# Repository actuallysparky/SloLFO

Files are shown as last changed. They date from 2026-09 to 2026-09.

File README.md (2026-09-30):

# SloLFO

SloLFO is an 8 HP slow Eurorack LFO module and a VCV Rack 2 plugin. The VCV plugin is availalbe prior to the eurorack module and is being used as an exploring ground for the user interface. Three phase-aligned outputs provide sine, triangle, and square CV. The module uses one push encoder and an 8×8 color matrix modeled on the Waveshare RP2350-Matrix hardware fork.

**Author for the VCV plugin: Bearamin.** Inspired by Patience, with thanks to the wonders of slow time.

## Try the VCV module

| Action | Result |
| --- | --- |
| Tap the encoder for under 0.5 seconds | Select Minutes, Hours, Days, or Months; the selected 4×4 color quadrant is bright. |
| Turn the encoder | Set 1–60 minutes, 1–24 hours, 1–64 days in half-day steps, or 1–64 fixed 30-day months. |
| Hold for 0.5 seconds | Preview the present voltage mode: four blue upper rows for 0–5 V, or blue upper and red lower rows for −5–5 V. |
| Continue holding to 2 seconds | Switch all three outputs immediately and update the preview; a longer hold does not switch again. |

Minutes and Hours show period as a colored pie. Days and Months fill the grid from the upper left, one pixel per day or month; half-day settings half-light the next pixel. At idle, a colored triangle remains static while one bright pixel follows phase. Its upper-half shape indicates unipolar output; bipolar uses the display's full height. The three CV outputs remain active together.

The plugin is a user-experience prototype. A fixed month is 30 days, so the longest setting is 1,920 days. The included firmware now targets the RP2350/8×8 module and follows the same front-panel controls and displays. Physical behavior remains to be checked on an assembled module.

## Contents

- [`vcv/`](vcv/) — Rack plugin C++ source, panel SVG, manifest, build files, and panel generator.
- [`firmware/`](firmware/) — RP2350/8×8 firmware source, local board definition, and build instructions.
- [`hardware/`](hardware/) — RP2350 carrier and 8×8 faceplate KiCad PCB files plus the custom footprints they use.
- [`bom/`](bom/) — a current board-derived parts list and an older priced Rev B workbook, with revision notes.
- [`docs/functional-spec.md`](docs/functional-spec.md) — proposed behavior and electrical architecture.
- [`docs/2350-fork-notes.md`](docs/2350-fork-notes.md) — RP2350 pin mapping and open hardware issues.

## Build the Rack plugin

Install the VCV Rack 2 plugin SDK and set `RACK_DIR` to its extracted `Rack-SDK` directory. The checked-in panel SVG lets a normal plugin build use the existing artwork; regenerating it from the faceplate requires KiCad's `kicad-cli` and Python 3.

```sh
cd vcv
make RACK_DIR=/absolute/path/to/Rack-SDK
make dist RACK_DIR=/absolute/path/to/Rack-SDK
```

The `.vcvplugin` package appears under `vcv/dist/`. The plugin manifest uses the `SlowLFOPrototype` slug and `Bearamin` author. The checked-in panel SVG is packaged as-is; run `make -C vcv panel` when the KiCad faceplate changes.

For a release package built from the current committed source, run:

```sh
RACK_DIR=/absolute/path/to/Rack-SDK ./vcv/build_release.sh
```

This uses `git archive HEAD` in a temporary directory, builds with the supplied Rack 2 SDK, and writes the plugin archive plus a SHA-256 checksum to `_local/releases/v2.0.6/`. Use a Rack 2.6.6 SDK for the current release. The script requires a clean tracked tree so the resulting package can be tied to a commit. The `.vcvplugin` contains `plugin.json`, the panel artwork, and the GPL license; the separate RP2350 firmware is not part of the Rack package.

The manually triggered [cross-platform release workflow](.github/workflows/release-cross-platform.yml) builds Windows x64 and Linux x64 packages from the fixed `v2.0.6` tag with their matching Rack 2.6.6 SDKs, checks package contents, and attaches packages, checksums, and build details to the private GitHub release. The macOS ARM64 package is built with the local release script above.

On macOS systems whose default Command Line Tools SDK reports an `arm64e.x1` linker error, set `SDKROOT` to a compatible Xcode SDK. This release was built with `SDKROOT=/Applications/Xcode.app/Contents/Developer/Platforms/MacOSX.platform/Developer/SDKs/MacOSX26.5.sdk`. The script also writes `BUILDINFO.txt` with the source commit, SDK, compiler, and platform used.

## License and project status

SloLFO is licensed under [GPL-3.0-or-later](LICENSE), the license identifier used by [VCV Core](https://github.com/VCVRack/Rack/blob/v2/Core.json). TUpdates to the plugin, firmware, and boards will be published here as the design evolves. See the [firmware build and pin map](firmware/README.md) and [hardware files](hardware/README.md).

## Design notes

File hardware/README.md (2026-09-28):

# Hardware

`Slow-LFO-8HP-Carrier-RevB_2350.kicad_pcb` and `Slow-LFO-8HP-Faceplate_8x8.kicad_pcb` are the RP2350/8×8 carrier and faceplate designs. `SlowLFO.pretty` contains the custom footprints referenced by the carrier, and `fp-lib-table` points KiCad to that directory.

The boards are the current design files in this private development repository. The carrier has open electrical and fit work; fabrication and validation are the next hardware milestones. See [RP2350 fork notes](../docs/2350-fork-notes.md) and the [functional specification](../docs/functional-spec.md) for the pin map and circuit design.

Open either PCB in KiCad to inspect or continue the layout. The matching RP2350 firmware source is in `../firmware/`.

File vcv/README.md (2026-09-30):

# Slow LFO for VCV Rack 2

This 8HP virtual module previews the proposed 8×8 RGB user experience. It generates ideal phase-aligned sine, triangle, and square outputs in either 0–5 V or −5–5 V. Its panel SVG is generated from the `Slow-LFO-8HP-Faceplate_8x8.kicad_pcb` front silk and copper artwork. VCV models the controls and timing; the hardware firmware and circuit are developed separately.

## Use

- Click the encoder to advance Minutes → Hours → Days → Months. Four 4×4 color quadrants fill the matrix; the bright quadrant is selected.
- Drag the encoder vertically or scroll over it to change period. The ranges are 1–60 minutes, 1–24 hours, 1–64 days in half-day steps, and 1–64 fixed 30-day months. Minutes and Hours fill a colored pie. Days and Months fill the 8×8 grid from the upper left, one pixel per day or month; the next day pixel is half-bright at half-day steps. A full violet grid represents a 64-month cycle.
- Hold the encoder for 0.5 seconds to preview the current voltage mode: four blue upper rows for 0–5 V, or blue upper and red lower rows for −5–5 V. Keep holding to 2 seconds to switch all outputs immediately; the preview changes with them. Further holding does nothing. Release between 0.5 and 2 seconds to leave the mode unchanged. A tap shorter than 0.5 seconds still advances the edit unit.
- After two seconds, the matrix returns to a static triangle glyph in the selected unit's color. The glyph stays visibly colored while one white, extra-bright pixel follows the shared phase. In 0–5 V mode the glyph and marker stay in the upper four rows; in −5–5 V mode they span the full matrix. All three CV jacks remain active at all times.
- On module creation and after switching simulated power back on, a 64-pixel spiral shows reserve-capacitor charging. The default is 15 real seconds, with 10- and 25-second comparison settings in the context menu. Phase and encoder edits pause while charging; CV outputs hold the saved phase. Simulated power off blanks the matrix and drives the output jacks to 0 V. Time acceleration does not accelerate charging.
- The module context menu also exposes 1×/60×/3600×/86400× time acceleration, forced phase, and simulated power off/on. These extra controls are VCV-only.
- Open the context menu to see the exact period. Connect the three output jacks to Rack's Scope to inspect their voltages.

The physical hardware's present sine/triangle RC filters support a provisional **10-second minimum target** for usable shape. The revised 1-minute minimum has ample calculated margin, pending bench measurement. A fixed month means 30 days, not a calendar month; 64 months is 1,920 days. The selected 0.33 F capacitor and 10 Ω charge resistor give an ideal 3.3-second RC constant; the actual reserve-ready delay is estimated at roughly **10–25 seconds**. The 15-second VCV animation is a UX approximation, not a measured capacitor model.

## Build and install

Install a Rack 2 plugin SDK and pass its `Rack-SDK` directory as `RACK_DIR`. The SDK is a build dependency, not project source. The checked-in `res/SlowLFO.svg` is packaged directly, so a plugin build does not require KiCad. When the faceplate changes, run `make -C vcv panel` from the repository root and commit the regenerated SVG; that explicit step requires Python 3 and `kicad-cli`. Set `KICAD_CLI` to its executable if it is not on `PATH`.

```sh
cd vcv
make -j4 RACK_DIR=/absolute/path/to/Rack-SDK
make dist RACK_DIR=/absolute/path/to/Rack-SDK
```

`dist/` contains a `.vcvplugin` package. Rack loads installed plugins at startup; restart Rack after installation. The module appears as **Slow LFO Prototype → Slow LFO**.

For a release build from committed source, run `RACK_DIR=/absolute/path/to/Rack-SDK ./vcv/build_release.sh` from the repository root. The script places the package and SHA-256 checksum under `_local/releases/<version>/` and checks that the package contains the manifest, artwork, and license. The current release target uses Rack SDK 2.6.6 on macOS ARM64; other architectures require their corresponding Rack SDK and a build on that platform or the official Rack plugin toolchain.
The script also writes `BUILDINFO.txt`. If the host's default macOS SDK cannot link the plugin, set `SDKROOT` to a compatible Xcode SDK before invoking the script.

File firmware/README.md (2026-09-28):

# RP2350-Matrix firmware

This Pico SDK firmware targets the Waveshare RP2350-Matrix with its 8×8 RGB display and the SloLFO carrier. It implements the VCV module's four literal period units, encoder gestures, static triangle phase view, colored selector, pie/calendar period views, and simultaneous sine, triangle, and square outputs. The hardware charging spiral follows measured reserve voltage; VCV uses a timed simulation.

## Build

Use Pico SDK 2.3.1 or newer and an Arm embedded GCC toolchain. From the repository root, set `PICO_SDK_PATH` to a local SDK checkout and run:

```sh
cmake -S firmware -B /tmp/slolfo-rp2350-build -G Ninja -DCMAKE_BUILD_TYPE=Release -DPICO_NO_PICOTOOL=1
cmake --build /tmp/slolfo-rp2350-build -j4
```

The build creates `slow_lfo.elf` and `slow_lfo.bin` in the build directory. With a suitable `picotool`, omit `-DPICO_NO_PICOTOOL=1` and set `-DSLOW_LFO_UF2=ON` to request UF2 output. The local board header selects RP2350A and the module's nominal 16 MB flash. The post-build check keeps the binary out of the final 64 KiB flash journal.

## Controls and outputs

- A tap shorter than 0.5 seconds advances Minutes → Hours → Days → Months and shows four 4×4 color quadrants, with the selected quadrant bright.
- Turning sets 1–60 minutes in 1-minute steps, 1–24 hours in 1-hour steps, 1–64 days in half-day steps, or 1–64 fixed 30-day months in 1-month steps. The first detent in a new unit clamps an out-of-range period to that unit's nearest endpoint. The period display returns to the waveform after two seconds.
- From 0.5 seconds of a press, the matrix previews the current output mode: blue upper rows for 0–5 V; blue upper and red lower rows for −5–5 V. At two seconds the mode switches once, immediately. Turning while pressed cancels the hold action.
- Minutes and Hours fill a color pie. Days and Months fill from the upper-left in calendar order. The idle triangle has a bright moving phase pixel and occupies only the upper four rows in unipolar mode.

GP10/11/12 generate sine/triangle/square PWM; GP13/14/15 read encoder A/B/push; GP26 senses the buck rail; GP27 senses the reserve capacitor; GP25 drives the WS2812 chain. The code assumes alternating physical LED rows. The board's ADC divider ratios are provisionally 1:2; 4.4 V fail, 4.75 V recover, and 4.55 V reserve-ready are prototype thresholds. Confirm the actual LED orientation, rail thresholds, and PWM-to-jack voltages on the assembled board before using a binary.

One shared 64-bit timer phase drives all three outputs at 100 Hz. Charging freezes the phase and encoder edits until the reserve threshold is met. The phase also freezes while unpowered; no backed-up RTC is present. The final 64 KiB of flash holds 256-byte CRC journal records with period, phase, voltage mode, and selected unit. It checkpoints hourly and appends an emergency record after buck loss, without erasing during reserve power. A red lower-right pixel indicates a failed flash operation or an invalid record found at boot. The 16 MB flash capacity, one-second hold-up margin, and interrupted-write recovery still require physical confirmation.

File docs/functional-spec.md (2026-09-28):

# Slow LFO — Rev B functional specification

Status: engineering prototype. The 8×8 RP2350 carrier and 22 × 22 mm faceplate opening are separate forks of the earlier RP2040 design. See [RP2350 fork notes](2350-fork-notes.md). The UX contract below is implemented in the VCV module and RP2350 firmware source. Electrical, physical, and power-cut acceptance on a built unit remain open.

## Product and interface

An 8HP, 3U Eurorack module produces simultaneous, phase-aligned SINE, TRIANGLE, and SQUARE CVs on three 3.5 mm TS jacks. The new controller/display target is the Waveshare **RP2350-Matrix** with its 8×8 RGB matrix. The legacy RP2040/5×5 carrier and schematic remain separate references until the new fork is electrically completed. One five-terminal, detented push encoder is the only control. The display sits above the encoder; the three jacks are below it. No rate CV, sync, output attenuator, or phase-reset control is included.

### UX timing and encoder contract

The revised prototype period range is **1 minute through 64 fixed 30-day months** (165,888,000 seconds, about 5.26 years). The four edit units are literal **minutes, hours, days, and months**: a displayed minute count means that many minutes per cycle, and a displayed month count means that many months per cycle. A fixed month is provisionally 30 days; this keeps periods deterministic without a clock or calendar date. Period is stored as an exact duration in seconds; changing period preserves instantaneous phase and keeps the three outputs phase-aligned.

| Edit unit | Color role | Selectable period | Encoder detent |
| --- | --- | --- | --- |
| Minutes | Cyan | 1–60 min | 1 min |
| Hours | Green | 1–24 h | 1 h |
| Days | Amber | 1–64 d | 0.5 d; one pixel per day, with the next pixel half-bright at half days |
| Months | Violet | 1–64 fixed 30-day months | 1 month; one pixel per month |

Endpoints intentionally overlap at 60 min = 1 h, 24 h = 1 d, and 30/60 d = 1/2 fixed months. Days and Months both fill the 64 pixels in row-major order from the upper left. In Days, 1 d lights one pixel, 1.5 d lights the next pixel at half brightness, and 64 d fills the grid. In Months, 1 month lights one pixel and 64 months fills the grid. The earlier 25-to-30-day setting gap is gone. The VCV prototype uses an exact-value context-menu label for observation; no text or number is drawn on the hardware display.

At idle, the matrix shows **one static triangle glyph** in the selected unit's color. Its full shape stays visibly colored, while one extra-bright white pixel travels along it to show the shared cycle phase. In UNI (0 to +5 V), the entire glyph and marker occupy only rows 0–3, leaving rows 4–7 dark; in BI (−5 to +5 V), they span the full eight-row height. This is a visual indication of output range; the three jacks continue to output sine, triangle, and square simultaneously. A **short press** (<500 ms) advances the selected edit unit Minutes → Hours → Days → Months → Minutes, displays a four-quadrant color selector with the selected quadrant dramatically brighter, and does not itself change period or phase. Each quadrant fills one 4×4 corner of the matrix, so the selector uses all 64 pixels. Turning the encoder edits the selected unit and shows its full-screen time display. If the existing period is outside that unit's range, the first detent lands on the nearest boundary; later detents move by its listed step. When it is already in range, the first detent moves by one step. No detent wraps at an endpoint. After about two seconds without input, return to the idle glyph. Unit hue remains fixed across selection and time displays.

In Minutes and Hours, the **entire 8×8 matrix** is a circular pie whose illuminated area represents the chosen period as a fraction of that unit's maximum. Boundary-pixel brightness may show fractional fill, but the display is intentionally qualitative. In Days and Months, the matrix is a 64-cell calendar that fills in row-major order from the upper left, one cell per selected day or fixed month. The whole matrix is available in time display because unit identity is carried by color; the four-quadrant selector appears only on short press.

Holding the encoder for **500 ms** replaces the matrix view with the *current* output mode: all upper four rows blue in UNI; upper four rows blue and lower four rows red in BI. Releasing between 500 ms and 2 seconds cancels the preview without changing mode or edit unit. At **2 seconds of continuous hold**, switch **all three outputs together** to the other voltage mode immediately and update the held preview immediately. Continuing to hold causes no further switches; release returns to the usual display. Turning during a press cancels its hold action. Changing voltage mode preserves phase and period, so jack voltage may jump at the switch instant. SINE/TRIANGLE endpoints and SQUARE levels are 0/+5 V in UNI and −5/+5 V in BI. At boot or on return from power loss, a 64-pixel spiral shall show reserve-charge progress from the measured CAP+ voltage to the validated ready threshold; do not use a fixed timer to decide physical readiness. Limit normal matrix brightness and blank it immediately on power failure. During charging, freeze phase advancement and ignore edits as described below.

The RP2350 firmware renders the 8×8 views above and edits literal time units. Unlike VCV's timed charging animation, the physical charging spiral fills from measured CAP+ voltage. The LED chain's alternating-row orientation is a current firmware assumption for physical confirmation.

## Circuit and pin assignment

J1 is a keyed 2×5 Eurorack IDC connector: pins 1–2 = −12 V, 3–8 = GND, 9–10 = +12 V. Verify physical pin 1, cable stripe, jack pinout, and faceplate fit before applying power. J2/J3/J4 tips are SINE_OUT/TRI_OUT/SQUARE_OUT; sleeves are GND.

The existing review schematic and original carrier name the RP2040 interface pins 1–20 as GPIO0–GPIO15 and GPIO26–GPIO29, pin 21 as 3V3, pin 22 as GND, and pin 23 as VSYS. They allocate GPIO2/3/4 to SINE_PWM/TRI_PWM/SQUARE_PWM, GPIO5/6/7 to encoder A/B/push, GPIO26/ADC0 to pre-isolation buck sense, GPIO27/ADC1 to reserve sense, and GPIO29 to the built-in WS2812 matrix. **This pin map does not describe the RP2350 fork.** The 20-hole RP2350 footprint maps PWM to GP10/11/12, encoder to GP13/14/15, buck/reserve senses to GP26/27, and onboard LED data to GP25; the RP2350 firmware uses these assignments. Confirm actual hole geometry, orientation, 5 V power pin, and common ground on a sample.

U3 is a TL074 DIP-14 on ±12 V. C6/C7 are local 100 nF rail decouplers; C8 is +12 V bulk, **not** backup energy. SINE/TRIANGLE retain two cascaded 3.3 kΩ/10 µF passive PWM filter poles. Add one approximately 3.3 kΩ/2.2 µF pole to SQUARE so 50% PWM produces a steady UNI low while output edges remain under roughly 20 ms; measure ripple and edge time before accepting the one-pole tradeoff. Use the fourth TL074 amplifier as a unity buffer for a shared 2.446 V reference made by a 10.5 kΩ/30.1 kΩ divider from U1 3V3. Each waveform amplifier retains nominal 12 kΩ feedback and changes its existing return resistor to 5.76 kΩ from the inverting input to the buffered reference. Nominally `Vout ≈ 3.0833 × Vfilter − 5.096 V` at a 3.3 V rail, giving roughly −5.10/+5.08 V unloaded. Use 330 Ω output series resistors provisionally and verify loaded endpoints and short behavior.

On the pin-header carrier, C9 is specified as KEMET C410C225K3R5TA, a 2.2 µF/25 V axial X7R ceramic mounted vertically with hand-formed leads at 2.50 mm pitch. Check the bent-lead clearance and effective capacitance under voltage bias before accepting the square response.

Use at least 12-bit PWM near 30 kHz. UNI samples map to 50–100% duty and BI to 0–100%; SQUARE uses only 50/100% UNI and 0/100% BI. UNI has about 11 bits of amplitude resolution. Adjust duty endpoints per channel only if measured gain/reference error requires it. At each jack, require nominal endpoints within ±5% into high impedance and 10 kΩ loads; record both load conditions. Measure square edge time and PWM ripple.

## Supply, reserve, and power loss

C11 uses the KYOCERA AVX SCMR14L334SRBB0 footprint (24 × 8 mm nominal board body, 14 mm height, 13.5 mm lead spacing). Its narrow dimension runs across the carrier at the old C11 center, with the existing copper intentionally left untouched for the owner's placement and routing pass. Pad 1 remains `CAP+`, pad 2 remains `GND`; confirm the sample's polarity mark before assembly. The 9 V rating provides headroom; the reserve still charges only from the 5 V buck through D2/R18. The 1-second worst-case hold-up requirement remains subject to measurement.

A through-hole 1 A buck, provisionally RECOM R-78B5.0-1.0, converts +12 V to `+5V_BUCK`. A Schottky diode supplies U1 VSYS normally. A separate Schottky and approximately 10 Ω, at least 3 W pulse-rated THT resistor charge `CAP+` on a KYOCERA AVX SCMR14L334SRBB0 0.33 F, 9 V supercapacitor. A third Schottky feeds VSYS from CAP+. C_HOLD must not discharge into the buck, TL074 rails, or jacks. Check regulator startup/capacitive-load limits and provide accessible +12 V, −12 V, +5V_BUCK, CAP+, VSYS, 3V3, and GND measurement pads.

GPIO26 senses +5V_BUCK **upstream of the isolation diodes** through a divider that keeps its input below 3.3 V. GPIO27 senses CAP+ through a second divider. Sample at least every 2 ms. Set fail threshold and hysteresis after rail measurements. On a falling upstream rail, send an all-off LED frame, capture period/phase/voltage mode, append one pre-erased flash page, and stop nonessential activity. No sector erase is permitted during hold-up. Require VSYS above the validated module operating limit for at least **1 second** after detection, including worst-case measured dark current, capacitance, ESR, aging, and diode drops.

At 10 Ω and nominal 0.33 F, the ideal charge time constant is 3.3 seconds. With an assumed 4.7 V charge ceiling, the ideal time to a provisional 4.55 V reserve-ready threshold is about **11.4 seconds**. The selected capacitor is specified at +30%/−10% capacitance tolerance; diode drop, regulator tolerance, and leakage widen the cold-start estimate to roughly **10–25 seconds**. It may take longer, or never assert, if the charge ceiling is too low. Measure the actual ceiling and set the threshold from worst-case hold-up. At boot restore phase and drive stationary CV values, but freeze phase advancement and encoder edits while the matrix shows a charging animation. The VCV prototype uses a 15-second default and selectable 10/25-second simulations; those are UX durations, not an electrical cap model. Start advancement only after CAP+ is ready. If cut during charging, the previous valid journal record is the fallback.

## Timing, flash, and recovery

Use a 64-bit monotonic microsecond timer and integer/fixed-point phase origin, not a 32-bit millisecond clock or repeated low-precision floating-point additions. Update all PWM duties at least 100 times per second from one shared phase. Period changes preserve instantaneous phase. After storage work, recompute duties from the current timer. Avoid long blocking delays.

Reserve an end-of-flash journal outside the firmware image. Each 256-byte page stores magic, format version, sequence, period, phase, UNI/BI mode, selected unit, and CRC. Scan for the newest valid record at boot. Checkpoint hourly and once on power fail, never per detent. Erase sectors only under stable power and maintain a pre-erased page. A torn emergency page falls back to the prior valid record. If no record exists, use 60 s, phase zero, UNI and write an initial checkpoint once the reserve is ready. Use one core and Pico SDK flash-safe execution so no code or interrupt reads execute-in-place flash during programming.

Phase **freezes while unpowered**. Advancing through an outage requires a backed-up RTC and a different contract. A 64-month setting places much stronger demands on clock stability, flash-journal wear, and long-running power-loss behavior than a 64-day setting; measure and budget those separately before claiming multi-year accuracy. Brownout or corrupt storage must never silently cause an arbitrary phase-zero restart. For the current *unbuffered* two-stage 3.3 kΩ/10 µF sine and triangle filters, an ideal equal-part small-signal model is `H(s) = 1 / (1 + 3sRC + (sRC)^2)`. It predicts sine fundamental gain of about 0.876 at a 1-second period, 0.994 at 5 seconds, and 0.998 at 10 seconds. At 10 seconds the triangle's third and fifth harmonics retain about 0.987 and 0.964 gain. Accordingly, **10 seconds is the provisional minimum hardware target for usable wave shapes**; 20 seconds is a cleaner margin for the triangle. This is calculated, not bench-verified, and does not include capacitor tolerance, output loading, PWM ripple, or actual op-amp behavior. A 1-minute minimum gives substantial margin with the present filters.

## Release evidence

### Issue disposition

| Issue found in the Rev A review | Rev B response | Remaining gate |
|---|---|---|
| No regulated Matrix power or correctly connected power pads | Add U2 5 V buck, diode-isolated VSYS, and Matrix 3V3/GND/VSYS net pads. The earlier Rev B board passed DRC; the current pin-header fork has zero unconnected items but remaining placement and silkscreen findings. | Verify the module header pin numbering, rear-mounted regulator lead order/clearance, keyed ribbon orientation, and current fork routing on real parts. |
| No cap reserve or power-loss signal | Add 0.33 F/9 V C11 behind D2/R18 charging path, D3 reserve path, and two ADC dividers. | Relocate C11 and reconcile its existing copper, then scope startup, fail threshold, dark current, worst-case hold-up, and flash-write completion. |
| 0–7 V analog gain and raw PWM square | Change gain/reference network for selectable 0–5 V or −5–5 V; add square RC pole. | Check output headroom, loaded endpoints, ripple, edges, and exact C9 part. |
| Fourth TL074 section unused | Buffer the 3.3 V-derived reference with U3D; the reference net is routed. | Check noise/offset under switching load. |
| Long-duration phase persistence incomplete | RP2350 firmware source has an hourly CRC journal and emergency record, 64-bit phase calculation, torn-page skip, startup freeze while charging, and a 16 MB board definition with the final 64 KiB reserved. | Power-cut and interrupted-write trials on actual hardware; confirm the module's flash part and reserved partition. |
| Matrix and encoder UX changed after Rev B firmware | RP2350 source now implements four literal minute/hour/day/month units, tap-to-advance quadrants, pie for minutes/hours, 64-cell calendar for days/months, a bright static triangle with one white phase pixel, and a measured-capacitor charging spiral. | Compare assembled 8×8 LED order, encoder direction/gestures, and long-period behavior with VCV. |
| Routed 8HP carrier had shorts/opens, missing schematic parity, and provisional footprints | The earlier Rev B board fork preserved the user's source and passed carrier/faceplate DRC; its board-derived schematic passed ERC and matched 115 connected pads on 32 nets. The current C11 footprint pass reports zero unconnected items, two C11 placement conflicts, and eight silkscreen warnings; the revised faceplate previously passed DRC. | Resolve current carrier DRC findings and independently review electrical topology and exact footprint/pin/height geometry; the earlier schematic was generated from that PCB and cannot provide independent topology validation. |

### Fabrication and acceptance

Before fabrication: resolve the current carrier's two C11 placement conflicts and eight silkscreen warnings, then repeat DRC after the owner's placement/routing pass; independently review circuit topology and actual part pinouts; compare Matrix, encoder, jacks, supercapacitor, rear-mounted regulator, and keyed cable to the footprints; confirm front/rear component heights and 8HP panel fit. The connected review schematic passes ERC but is board-derived, and the revised faceplate previously passed DRC. Before acceptance: current-limited ±12 V bring-up; regulator heat/noise; both voltage modes on all three jacks into high impedance and 10 kΩ; square edges and PWM ripple; one-day timing comparison; encoder/UI checks; repeated phase-varied power cuts including interrupted flash writes. Scope +5V_BUCK, CAP+, VSYS, and a firmware save marker together to prove at least 1 second of valid hold-up and newest-valid recovery. A dedicated save marker/test pad and accessible rail test pads still need to be finalized for that measurement. Source/build, electrical, runtime, physical fit, and fabrication are separate evidence.

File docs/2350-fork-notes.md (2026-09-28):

# RP2350-Matrix 8×8 carrier fork

`Slow-LFO-8HP-Carrier-RevB_2350.kicad_pcb` is a copy of the saved
`_pinheaders` carrier with U1 alone replaced by a centered, front-mounted
Waveshare RP2350-Matrix 8×8 module footprint. The module's USB-C connector is
at the top, behind its LED side. All existing tracks, vias, zones, other
footprints, and board edges are unchanged. The new U1 footprint uses the 20
through-hole edge connections; the eight small bottom-edge GPIO solder pads
and DOUT are intentionally absent, since this is the header-mount variant.

| Carrier net | RP2350-Matrix pin | U1 pad |
| --- | --- | ---: |
| `VSYS` | `5V` | 1 |
| `GND` | `GND` | 2 |
| `3V3` | `3V3` | 3 |
| `CAP_SENSE` | `GP27` / ADC1 | 6 |
| `BUCK_SENSE` | `GP26` / ADC0 | 7 |
| `PWM_SINE` | `GP10` | 11 |
| `PWM_TRI` | `GP11` | 12 |
| `PWM_SQUARE` | `GP12` | 13 |
| `ENC_A` | `GP13` | 14 |
| `ENC_B` | `GP14` | 15 |
| `ENC_SW` | `GP15` | 16 |

Other edge pins are left unconnected. `GP25` controls the onboard WS2812
matrix and needs no carrier net. The RP2350 firmware uses GPIO 10–12
for waveform PWM, GPIO 13–15 for the encoder, GPIO 26–27 for power sensing,
and GPIO 25 for the LEDs. `VSYS` is the carrier's existing net name; the module pin is
marked `5V` by Waveshare.

The outline and 2.54 mm edge-hole pitch follow Waveshare's [25 × 25 mm
mechanical drawing](https://www.waveshare.com/img/devkit/RP2350-Matrix/RP2350-Matrix-details-size.jpg);
the pin names/order follow its [pinout image](https://www.waveshare.com/img/devkit/RP2350-Matrix/RP2350-Matrix-details-inter.jpg).
The Ø1.0 mm drill and Ø1.7 mm annulus are inherited header assumptions, not
dimensions specified by Waveshare. Dry-fit a purchased module and chosen
headers before fabrication. The separate `Slow-LFO-8HP-Faceplate_8x8.kicad_pcb`
has a 22 × 22 mm LED opening centered over the 25 × 25 mm U1 module at
faceplate drawing coordinate (67.37, 46.5475) mm. This leaves a nominal
1.5 mm module rim on all four sides. The actual LED envelope, header stack,
panel-to-module spacing, rear USB clearance, LED current budget, nearby carrier
component fit, and all new U1 copper escapes remain subjects for the hardware
layout and physical validation work.

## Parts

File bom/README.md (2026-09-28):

# BOM revisions

- `board-parts-2350.csv` was exported by KiCad from the included RP2350 carrier PCB. It lists its saved references, values, footprints, quantities, and DNP flags. It has no verified sourcing or prices.
- `RevB-pricing-2026-09-24.xlsx` is an unchanged copy of the earlier priced Rev B workbook. **It does not match the included carrier**: its U1 row specifies the RP2040 5×5 module, and its C11 row specifies a 1 F/5.4 V capacitor. The saved RP2350 board specifies an RP2350 8×8 module and 0.33 F/9 V C11. Its prices and ordering gates are historical, not a current purchase list.

Reconcile every line against the finished schematic, physical parts, and current storefront availability before ordering.

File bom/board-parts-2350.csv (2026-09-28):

Refs | Value | Footprint | Qty | DNP
C2 | 10uF | SlowLFO:CP_Radial_D5.0mm_P2.00mm_CenterLabel | 1
C3 | 10uF | SlowLFO:CP_Radial_D5.0mm_P2.00mm_CenterLabel | 1
C4 | 10uF | SlowLFO:CP_Radial_D5.0mm_P2.00mm_CenterLabel | 1
C5 | 10uF | SlowLFO:CP_Radial_D5.0mm_P2.00mm_CenterLabel | 1
C6 | 100nF | SlowLFO:C_Disc_D5.0mm_W2.5mm_P5.00mm_CenterLabel | 1
C7 | 100nF | SlowLFO:C_Disc_D5.0mm_W2.5mm_P5.00mm_CenterLabel | 1
C8 | 10uF | SlowLFO:CP_Radial_D5.0mm_P2.00mm_CenterLabel | 1
C9 | 2u2 X7R 25V | SlowLFO:C410_Aximax_Axial_Vertical_P2.50mm_HandFormed | 1
C11 | 0.33F 9V | SlowLFO:SCMR14L334SRBB0 | 1
D1 | 1N5819 | Diode_THT:D_DO-41_SOD81_P2.54mm_Vertical_AnodeUp | 1
D2 | 1N5819 | Diode_THT:D_DO-41_SOD81_P2.54mm_Vertical_AnodeUp | 1
D3 | 1N5819 | Diode_THT:D_DO-41_SOD81_P2.54mm_Vertical_AnodeUp | 1
ENC1 | A/B/C plus switch | Rotary_Encoder:RotaryEncoder_Alps_EC11E-Switch_Vertical_H20mm_CircularMountingHoles | 1
J1 | 10pin IDC keyed | Connector_IDC:IDC-Header_2x05_P2.54mm_Latch_Vertical | 1
J2 | Jack_3.5mm_QingPu_WQP-PJ398SM_Vertical_CircularHoles | SlowLFO:Jack_3.5mm_QingPu_WQP-PJ398SM_Vertical_CircularHoles_J2 | 1
J3 | Jack_3.5mm_QingPu_WQP-PJ398SM_Vertical_CircularHoles | SlowLFO:Jack_3.5mm_QingPu_WQP-PJ398SM_Vertical_CircularHoles_J3 | 1
J4 | Jack_3.5mm_QingPu_WQP-PJ398SM_Vertical_CircularHoles | SlowLFO:Jack_3.5mm_QingPu_WQP-PJ398SM_Vertical_CircularHoles_J4 | 1
R1 | 3k3 | SlowLFO:R_Axial_DIN0207_L6.3mm_D2.5mm_P5.08mm_Vertical_CenterLabel | 1
R2 | 3k3 | SlowLFO:R_Axial_DIN0207_L6.3mm_D2.5mm_P5.08mm_Vertical_CenterLabel | 1
R3 | 12k | SlowLFO:R_Axial_DIN0207_L6.3mm_D2.5mm_P5.08mm_Vertical_CenterLabel | 1
R4 | 5k76 | SlowLFO:R_Axial_DIN0207_L6.3mm_D2.5mm_P5.08mm_Vertical_CenterLabel | 1
R5 | 330R | SlowLFO:R_Axial_DIN0207_L6.3mm_D2.5mm_P5.08mm_Vertical_CenterLabel | 1
R6 | 3k3 | SlowLFO:R_Axial_DIN0207_L6.3mm_D2.5mm_P5.08mm_Vertical_CenterLabel | 1
R7 | 3k3 | SlowLFO:R_Axial_DIN0207_L6.3mm_D2.5mm_P5.08mm_Vertical_CenterLabel | 1
R8 | 12k | SlowLFO:R_Axial_DIN0207_L6.3mm_D2.5mm_P5.08mm_Vertical_CenterLabel | 1
R9 | 5k76 | SlowLFO:R_Axial_DIN0207_L6.3mm_D2.5mm_P5.08mm_Vertical_CenterLabel | 1
R10 | 330R | SlowLFO:R_Axial_DIN0207_L6.3mm_D2.5mm_P5.08mm_Vertical_CenterLabel | 1
R11 | 12k | SlowLFO:R_Axial_DIN0207_L6.3mm_D2.5mm_P5.08mm_Vertical_CenterLabel | 1
R12 | 5k76 | SlowLFO:R_Axial_DIN0207_L6.3mm_D2.5mm_P5.08mm_Vertical_CenterLabel | 1
R13 | 330R | SlowLFO:R_Axial_DIN0207_L6.3mm_D2.5mm_P5.08mm_Vertical_CenterLabel | 1
R14 | 10k5 | SlowLFO:R_Axial_DIN0207_L6.3mm_D2.5mm_P2.54mm_Vertical_CenterLabel | 1
R15 | 30k1 | SlowLFO:R_Axial_DIN0207_L6.3mm_D2.5mm_P2.54mm_Vertical_CenterLabel | 1
R16 | 3k3 | SlowLFO:R_Axial_DIN0207_L6.3mm_D2.5mm_P2.54mm_Vertical_CenterLabel | 1
R18 | 10R >=3W pulse | SlowLFO:ChargeResistor_3W | 1
R19 | 10k | SlowLFO:R_Axial_DIN0207_L6.3mm_D2.5mm_P2.54mm_Vertical_CenterLabel | 1
R20 | 10k | SlowLFO:R_Axial_DIN0207_L6.3mm_D2.5mm_P2.54mm_Vertical_CenterLabel | 1
R21 | 10k | SlowLFO:R_Axial_DIN0207_L6.3mm_D2.5mm_P2.54mm_Vertical_CenterLabel | 1
R22 | 10k | SlowLFO:R_Axial_DIN0207_L6.3mm_D2.5mm_P2.54mm_Vertical_CenterLabel | 1
U1 | RP2350-Matrix | SlowLFO:RP2350-Matrix_8x8_THT | 1
U2 | R-78B5.0-1.0 | SlowLFO:RECOM_R78B5.0_Rear | 1
U3 | TL074 | Package_DIP:DIP-14_W7.62mm | 1

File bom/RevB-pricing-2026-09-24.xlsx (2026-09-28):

Slow LFO · 8 HP · Rev B BOM
Pricing snapshot: 24 Sep 2026. USD. Tax, shipping, tariff and assembly excluded.
GBP → USD assumption | 1.3210 |  | Editable exchange-rate input
Mouser priced subtotal | $25.45 |  | Includes budget prices and backordered C11. Not an orderable single-cart total.
Other stores priced subtotal | $16.81 |  | Waveshare + Thonk; GBP converted with B5.
Priced materials subtotal | $42.26
Complete build cost | TBD |  | TBD until encoder, knob, PCB, faceplate and blocked fit choices are resolved.
Category | References | Part / specification | Manufacturer part / item | Storefront | Qty needed | Order units | Unit price | CCY | USD / unit | Line total USD | Sourcing / fit | Product link
Module | U1 | 5×5 LED RP2040 module | RP2040-Matrix / SKU 24594 | Waveshare | 1 | 1 | 7.99 | USD | $7.99 | $7.99 | OTHER STORE | Open product (https://www.waveshare.com/product/rp2040-matrix.htm)
Power | U2 | 5 V 1 A switching regulator | R-78B5.0-1.0 | Mouser | 1 | 1 | 11.67 | USD | $11.67 | $11.67 | FIT CHECK | Open product (https://www.mouser.com/en/ProductDetail/RECOM-Power/R-78B5.0-1.0)
Analog | U3 | Quad operational amplifier, DIP-14 | TL074CN | Mouser | 1 | 1 | 1.07 | USD | $1.07 | $1.07 | SELECTED | Open product (https://www.mouser.com/ProductDetail/Texas-Instruments/TL074CN)
Control | ENC1 | Push rotary encoder, user-purchased | Exact MPN unknown | Owner supplied | 1 | 1 |  | USD |  |  | FIT CHECK
Power | J1 | Keyed 2×5 2.54 mm Eurorack power header | 71918-210LF | Mouser | 1 | 1 | 1.40 | USD | $1.40 | $1.40 | FIT CHECK | Open product (https://www.mouser.com/en/ProductDetail/Amphenol-FCI/71918-210LF)
I/O | J2, J3, J4 | 3.5 mm switched mono jacks | WQP518MA / PJ398SM compatible | Thonk | 3 | 3 | 0.38 | GBP | $0.50 | $1.51 | OTHER STORE | Open product (https://www.thonk.co.uk/shop/thonkiconn/)
Power | D1, D2, D3 | Schottky diode, DO-41 | 1N5819-E3/73 | Mouser | 3 | 3 | 0.76 | USD | $0.76 | $2.28 | SELECTED | Open product (https://www.mouser.com/en/ProductDetail/Vishay-Semiconductors/1N5819-E3-73)
Analog | C2, C3, C4, C5, C8 | 10 µF 50 V radial electrolytic, 5 mm body, 2 mm pitch | 860160672009 | Mouser | 5 | 5 | 0.14 | USD | $0.14 | $0.70 | SELECTED | Open product (https://www.mouser.com/ProductDetail/Wurth-Elektronik/860160672009)
Analog | C6, C7 | 100 nF 50 V X7R radial ceramic, 5 mm pitch | K104K10X7RF5TH5 | Mouser | 2 | 2 | 0.27 | USD | $0.27 | $0.54 | SELECTED | Open product (https://www.mouser.com/en/ProductDetail/Vishay-BC-Components/K104K10X7RF5TH5)
Analog | C9 | 2.2 µF 25 V X7R radial ceramic candidate | C410C225K3R5TA | Mouser | 1 | 1 | 0.45 | USD | $0.45 | $0.45 | PCB CHANGE | Open product (https://www.mouser.com/ProductDetail/KEMET/C410C225K3R5TA)
Power | C11 | 1 F 5.4 V supercapacitor, radial | SCMR18D105SRBB0 | Mouser | 1 | 1 | 5.06 | USD | $5.06 | $5.06 | BACKORDER | Open product (https://www.mouser.com/ProductDetail/KYOCERA-AVX/SCMR18D105SRBB0)
Resistors | R1, R2, R6, R7, R16 | 3.3 kΩ 1% 0.25 W axial | MFR-25FBF52-3K3 | Mouser | 5 | 5 | 0.10 | USD | $0.10 | $0.50 | SELECTED | Open product (https://www.mouser.com/en/ProductDetail/YAGEO/MFR-25FBF52-3K3)
Resistors | R3, R8, R11 | 12 kΩ 1% 0.25 W axial | MFR-25FRF52-12K | Mouser | 3 | 3 | 0.10 | USD | $0.10 | $0.30 | PRICE EST. | Open product (https://www.mouser.com/ProductDetail/YAGEO/MFR-25FRF52-12K)
Resistors | R4, R9, R12 | 5.76 kΩ 1% 0.25 W axial | MFR-25FRF52-5K76 | Mouser | 3 | 3 | 0.10 | USD | $0.10 | $0.30 | PRICE EST. | Open product (https://www.mouser.com/ProductDetail/YAGEO/MFR-25FRF52-5K76)
Resistors | R5, R10, R13 | 330 Ω 1% 0.25 W axial | MFR-25FRF52-330R | Mouser | 3 | 3 | 0.10 | USD | $0.10 | $0.30 | SELECTED | Open product (https://www.mouser.com/en/ProductDetail/YAGEO/MFR-25FRF52-330R)
Resistors | R14 | 10.5 kΩ 1% 0.25 W axial | MFR-25FBF52-10K5 | Mouser | 1 | 1 | 0.10 | USD | $0.10 | $0.10 | PRICE EST. | Open product (https://www.mouser.com/ProductDetail/YAGEO/MFR-25FBF52-10K5)
Resistors | R15 | 30.1 kΩ 1% 0.25 W axial | MFR-25FRF52-30K1 | Mouser | 1 | 1 | 0.10 | USD | $0.10 | $0.10 | SELECTED | Open product (https://www.mouser.com/en/ProductDetail/YAGEO/MFR-25FRF52-30K1)
Resistors | R19, R20, R21, R22 | 10 kΩ 1% 0.25 W axial | MFR-25FRF52-10K | Mouser | 4 | 4 | 0.10 | USD | $0.10 | $0.40 | PRICE EST. | Open product (https://www.mouser.com/ProductDetail/YAGEO/MFR-25FRF52-10K)
Power | R18 | 10 Ω 3 W axial charge resistor | FMP300JR-73-10R | Mouser | 1 | 1 | 0.28 | USD | $0.28 | $0.28 | FIT CHECK | Open product (https://www.mouser.com/en/ProductDetail/YAGEO/FMP300JR-73-10R)
Assembly | J2–J4 nuts | Knurled 3.5 mm jack nuts, bag of 50 | Thonkiconn knurled nuts 50-pack | Thonk | 3 | 1 | 1.89 | GBP | $2.50 | $2.50 | OTHER STORE | Open product (https://www.thonk.co.uk/shop/thonkiconn/)
Assembly | J2–J4 washers | Jack washers, bag of 50 | Thonkiconn washers 50-pack | Thonk | 3 | 1 | 1.99 | GBP | $2.63 | $2.63 | OTHER STORE | Open product (https://www.thonk.co.uk/shop/thonkiconn/)
Assembly | Power ribbon | 10-to-16-pin 15 cm Eurorack ribbon cable | 10–16 pin ribbon cable 15 cm | Thonk | 1 | 1 | 1.66 | GBP | $2.19 | $2.19 | OTHER STORE | Open product (https://www.thonk.co.uk/shop/eurorack-power-cables/)
Assembly | Panel screws | M3 rack screws for 8 HP panel | Case-dependent M3 screws | Owner supplied | 2 | 2 |  | USD |  |  | FIT CHECK
Assembly | Encoder knob | 6 mm shaft knob matching purchased encoder | Exact MPN unknown | Owner supplied | 1 | 1 |  | USD |  |  | FIT CHECK
Fabrication | Carrier PCB | 8 HP carrier PCB, latest Rev B files | Slow-LFO-8HP-Carrier-RevB | Fabricator TBD | 1 | 1 |  | USD |  |  | QUOTE NEEDED
Fabrication | Faceplate | 8 HP drilled faceplate | Slow-LFO-8HP-Faceplate | Fabricator TBD | 1 | 1 |  | USD |  |  | QUOTE NEEDED
 |  |  |  | PCB fitted references | 41 |  | Expected 41 |  | Priced sum | $42.26
Ordering gate | C9 footprint is not a verified match; C11 is backordered; encoder has no exact manufacturer SKU; custom PCB/faceplate need quotes.
Storefront limit | Exact RP2040-Matrix and QingPu-compatible jacks were not found at Mouser. Three component storefronts plus fabrication are currently required.

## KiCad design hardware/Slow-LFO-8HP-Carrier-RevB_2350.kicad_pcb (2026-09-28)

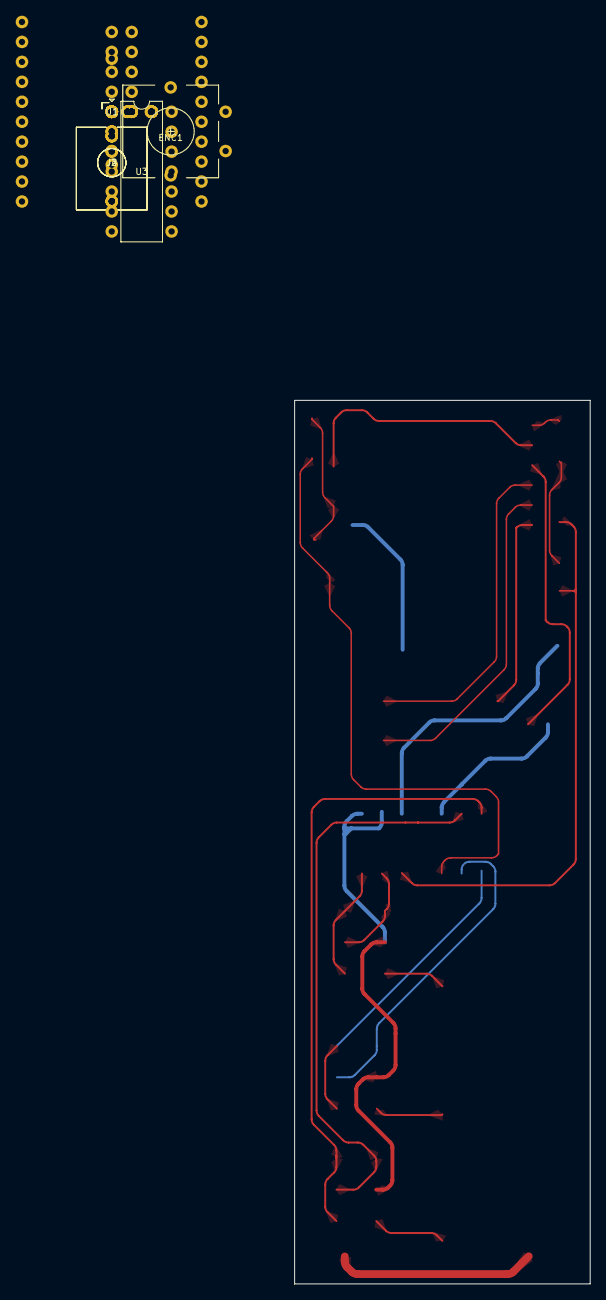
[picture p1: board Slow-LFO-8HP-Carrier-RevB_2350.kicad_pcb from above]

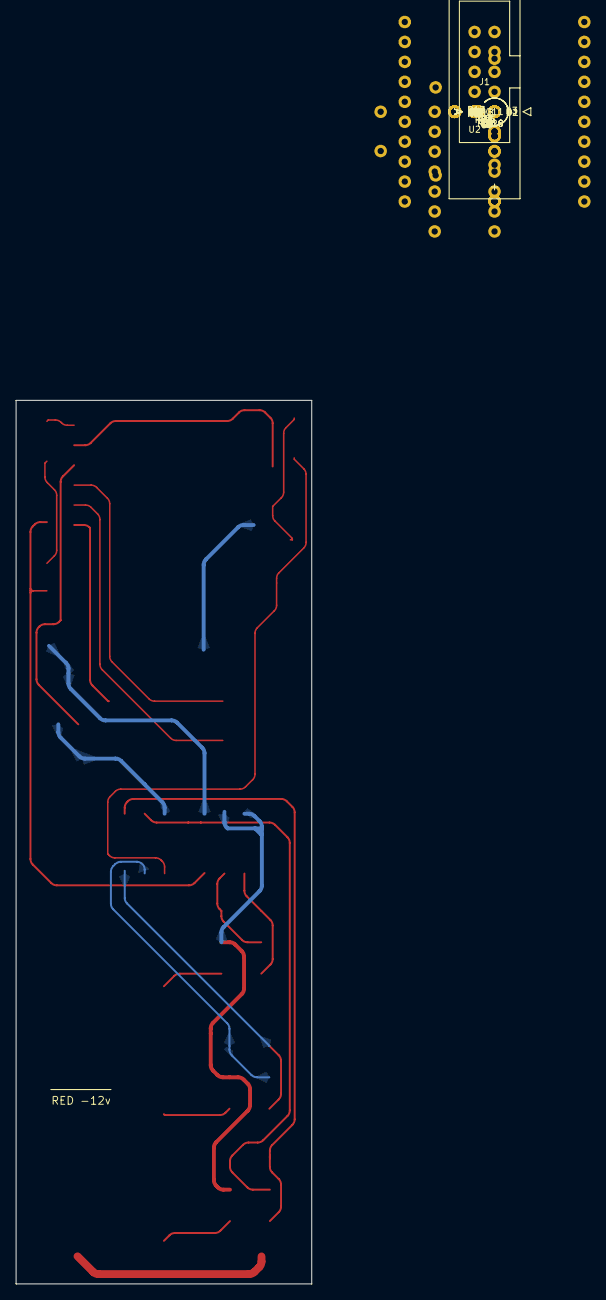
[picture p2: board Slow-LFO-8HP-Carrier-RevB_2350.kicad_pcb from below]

Board: 4 copper layers, 37.6 x 112.5 mm, 41 parts (35 on the bottom side), 32 nets.

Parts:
C2, C3, C4, C5, C8: 10uF; CP_Radial_D5.0mm_P2.00mm_CenterLabel
C6, C7: 100nF; C_Disc_D5.0mm_W2.5mm_P5.00mm_CenterLabel
C9: 2u2 X7R 25V; C410_Aximax_Axial_Vertical_P2.50mm_HandFormed
C11: 0.33F 9V; SCMR14L334SRBB0
D1, D2, D3: 1N5819; D_DO-41_SOD81_P2.54mm_Vertical_AnodeUp
ENC1: A/B/C plus switch; RotaryEncoder_Alps_EC11E-Switch_Vertical_H20mm_CircularMoun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
J1: 10pin IDC keyed; IDC-Header_2x05_P2.54mm_Latch_Vertical
J2: Jack_3.5mm_QingPu_WQP-PJ398SM_Vertical_CircularHo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; Jack_3.5mm_QingPu_WQP-PJ398SM_Vertical_CircularHoles_J2
J3: Jack_3.5mm_QingPu_WQP-PJ398SM_Vertical_CircularHo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; Jack_3.5mm_QingPu_WQP-PJ398SM_Vertical_CircularHoles_J3
J4: Jack_3.5mm_QingPu_WQP-PJ398SM_Vertical_CircularHo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; Jack_3.5mm_QingPu_WQP-PJ398SM_Vertical_CircularHoles_J4
R1, R2, R6, R7: 3k3; R_Axial_DIN0207_L6.3mm_D2.5mm_P5.08mm_Vertical_CenterLabel
R3, R8, R11: 12k; R_Axial_DIN0207_L6.3mm_D2.5mm_P5.08mm_Vertical_CenterLabel
R4, R9, R12: 5k76; R_Axial_DIN0207_L6.3mm_D2.5mm_P5.08mm_Vertical_CenterLabel
R5, R10, R13: 330R; R_Axial_DIN0207_L6.3mm_D2.5mm_P5.08mm_Vertical_CenterLabel
R14: 10k5; R_Axial_DIN0207_L6.3mm_D2.5mm_P2.54mm_Vertical_CenterLabel
R15: 30k1; R_Axial_DIN0207_L6.3mm_D2.5mm_P2.54mm_Vertical_CenterLabel
R16: 3k3; R_Axial_DIN0207_L6.3mm_D2.5mm_P2.54mm_Vertical_CenterLabel
R18: 10R >=3W pulse; ChargeResistor_3W
R19, R20, R21, R22: 10k; R_Axial_DIN0207_L6.3mm_D2.5mm_P2.54mm_Vertical_CenterLabel
U1: RP2350-Matrix; RP2350-Matrix_8x8_THT
U2: R-78B5.0-1.0; RECOM_R78B5.0_Rear
U3: TL074; DIP-14_W7.62mm

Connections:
3V3: R14.1, U1.3
+5V_BUCK: D1.1, D2.1, R19.1, U2.3
+12V: C6.1, C8.1, J1.9, J1.10, U2.1, U3.4
-12V: C7.1, J1.1, J1.2, U3.11
BUCK_SENSE: R19.2, R20.1, U1.7
CAP+: C11.1, D3.1, R18.2, R21.1
CAP_SENSE: R21.2, R22.1, U1.6
CHARGE_IN: D2.2, R18.1
ENC_A: ENC1.A, U1.14
ENC_B: ENC1.B, U1.15
ENC_SW: ENC1.S2, U1.16
GND: C2.2, C3.2, C4.2, C5.2, C6.2, C7.2, C8.2, C9.2, C11.2, ENC1.C, ENC1.S1, J1.3, J1.4, J1.5, J1.6, J1.7, J1.8, J2.S, J3.S, J4.S, R15.2, R20.2, R22.2, U1.2, U2.2
PWM_SINE: R1.1, U1.11
PWM_SQUARE: R16.1, U1.13
PWM_TRI: R6.1, U1.12
REF_DIV: R14.2, R15.1, U3.12
SINE_BUF: R3.1, R5.1, U3.1
SINE_F1: C2.1, R1.2, R2.1
SINE_F2: C3.1, R2.2, U3.3
SINE_NFB: R3.2, R4.1, U3.2
SINE_OUT: J2.T, R5.2
SQUARE_BUF: R11.1, R13.1, U3.8
SQUARE_F1: C9.1, R16.2, U3.10
SQUARE_NFB: R11.2, R12.1, U3.9
SQUARE_OUT: J4.T, R13.2
TRI_BUF: R8.1, R10.1, U3.7
TRI_F1: C4.1, R6.2, R7.1
TRI_F2: C5.1, R7.2, U3.5
TRI_NFB: R8.2, R9.1, U3.6
TRI_OUT: J3.T, R10.2
VREF_2V45: R4.2, R9.2, R12.2, U3.13, U3.14
VSYS: D1.2, D3.2, U1.1

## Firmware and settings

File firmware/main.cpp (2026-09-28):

#include <algorithm>
#include <array>
#include <cmath>
#include <cstdint>
#include <cstring>
#include <utility>
#include "pico/stdlib.h"
#include "pico/flash.h"
#include "hardware/adc.h"
#include "hardware/clocks.h"
#include "hardware/flash.h"
#include "hardware/pio.h"
#include "hardware/pio_instructions.h"
#include "hardware/pwm.h"
#include "hardware/watchdog.h"

// Electrical contract: the board's divider ratio is 1:2 on both ADC inputs.
// These thresholds are prototype defaults; scope the rails and recalibrate.
namespace {
constexpr uint PWM_SINE = 10, PWM_TRI = 11, PWM_SQUARE = 12;
constexpr uint ENC_A = 13, ENC_B = 14, ENC_PUSH = 15;
constexpr uint BUCK_ADC = 26, CAP_ADC = 27, LED_PIN = 25;
constexpr uint32_t PWM_TOP = 4095;
constexpr uint64_t SECOND_US = 1000000ULL;
constexpr uint64_t DAY_US = 86400ULL * SECOND_US;
constexpr uint64_t MONTH_US = 30ULL * DAY_US;
constexpr uint64_t PERIOD_MIN_US = 60ULL * SECOND_US;
constexpr uint64_t PERIOD_MAX_US = 64ULL * MONTH_US;
constexpr uint64_t MINIMUM_US[4] = {PERIOD_MIN_US, 3600ULL * SECOND_US, DAY_US, MONTH_US};
constexpr uint64_t MAXIMUM_US[4] = {3600ULL * SECOND_US, DAY_US, 64ULL * DAY_US, PERIOD_MAX_US};
constexpr uint64_t STEP_US[4] = {60ULL * SECOND_US, 3600ULL * SECOND_US, DAY_US / 2, MONTH_US};
constexpr uint32_t FLASH_BYTES = 16U * 1024U * 1024U;
constexpr uint32_t JOURNAL_BYTES = 64U * 1024U;
constexpr uint32_t JOURNAL_OFFSET = FLASH_BYTES - JOURNAL_BYTES;
constexpr uint32_t PAGE_BYTES = 256, SECTOR_BYTES = 4096;
constexpr uint32_t PAGE_COUNT = JOURNAL_BYTES / PAGE_BYTES;
constexpr uint32_t MAGIC = 0x534C4632; // SLF2; incompatible with the older RP2040 journal.
constexpr uint32_t FORMAT = 2;
constexpr uint32_t BUCK_FAIL_MV = 4400;
constexpr uint32_t BUCK_RECOVER_MV = 4750;
constexpr uint32_t CAP_READY_MV = 4550;
constexpr uint32_t CAP_READY_HYST_MV = 4450;
constexpr uint64_t HOUR_US = 3600ULL * 1000000ULL;
constexpr double TAU = 6.283185307179586;
constexpr int MATRIX_SIDE = 8, MATRIX_CELLS = 64;
constexpr int TRIANGLE_PATH_BI[] = {32,24,17,9,2,11,19,28,36,45,53,62,55,47,39};
constexpr int TRIANGLE_PATH_UNI[] = {16,8,9,1,2,3,11,12,20,21,29,30,31,23};

struct Color { uint8_t r, g, b; };
constexpr Color UNIT_COLOR[4] = {
    {4, 19, 25},   // minutes: cyan
    {6, 25, 11},   // hours: green
    {25, 16, 3},   // days: amber
    {23, 7, 25},   // months: violet
};

struct __attribute__((packed)) Record {
    uint32_t magic, format, seq;
    uint64_t period_us;
    uint32_t phase_q32;
    uint8_t bipolar;
    uint8_t selected_unit;
    uint8_t reserved[226];
    uint32_t crc;
};
static_assert(sizeof(Record) == PAGE_BYTES);

uint64_t period_us = PERIOD_MIN_US;
uint32_t base_phase = 0;
uint64_t anchor_us = 0;
bool bipolar = false;
bool reserve_ready = false;
bool flash_error = false;
bool fallback_used = false;
bool power_failed = false;
uint8_t selected_unit = 0;
uint8_t display_view = 0; // 0 waveform, 1 selector, 2 period
uint64_t view_deadline_us = 0;
bool mode_hold_preview = false;
uint32_t journal_seq = 0;
int newest_page = -1;
uint64_t next_checkpoint_us = 0;
PIO led_pio = pio0;
uint led_sm = 0;
constexpr uint WS_T1=2, WS_T2=5, WS_T3=3;
const uint16_t ws_instructions[] = {
    static_cast<uint16_t>(pio_encode_out(pio_x,1)|pio_encode_sideset(1,0)|pio_encode_delay(WS_T3-1)),
    static_cast<uint16_t>(pio_encode_jmp_not_x(3)|pio_encode_sideset(1,1)|pio_encode_delay(WS_T1-1)),
    static_cast<uint16_t>(pio_encode_jmp(0)|pio_encode_sideset(1,1)|pio_encode_delay(WS_T2-1)),
    static_cast<uint16_t>(pio_encode_nop()|pio_encode_sideset(1,0)|pio_encode_delay(WS_T2-1)),
};
const pio_program ws_program={ws_instructions,4,-1};

uint32_t crc32(const uint8_t *data, size_t n) {
    uint32_t crc = 0xffffffffu;
    for (size_t i=0; i<n; ++i) {
        crc ^= data[i];
        for (int bit=0; bit<8; ++bit) crc=(crc>>1)^((crc&1u)?0xedb88320u:0u);
    }
    return ~crc;
}

const uint8_t *page_address(uint32_t page) {
    return reinterpret_cast<const uint8_t *>(XIP_BASE + JOURNAL_OFFSET + page*PAGE_BYTES);
}
bool erased(uint32_t page) {
    const uint8_t *p=page_address(page);
    for (uint32_t i=0;i<PAGE_BYTES;++i) if (p[i]!=0xff) return false;
    return true;
}
bool valid(const Record &r) {
    return r.magic==MAGIC && r.format==FORMAT && r.period_us>=PERIOD_MIN_US &&
        r.period_us<=PERIOD_MAX_US && r.bipolar<=1 && r.selected_unit<4 &&
        crc32(reinterpret_cast<const uint8_t*>(&r),PAGE_BYTES-4)==r.crc;
}
void scan_journal() {
    uint32_t nonempty=0;
    for (uint32_t p=0;p<PAGE_COUNT;++p) {
        if (erased(p)) continue;
        ++nonempty;
        const Record &r=*reinterpret_cast<const Record*>(page_address(p));
        if (!valid(r)) {fallback_used=true; continue;}
        if (newest_page<0 || static_cast<int32_t>(r.seq-journal_seq)>0) {
            newest_page=static_cast<int>(p); journal_seq=r.seq;
            period_us=r.period_us; base_phase=r.phase_q32; bipolar=r.bipolar!=0;
            selected_unit=r.selected_unit;
        }
    }
    if (newest_page<0 && nonempty) fallback_used=true;
    anchor_us=time_us_64();
}

uint32_t phase_at(uint64_t now) {
    // Modulo bounds the quotient for periods as long as 64 fixed months.
    uint64_t remainder=(now-anchor_us)%period_us;
    uint32_t advance=static_cast<uint32_t>((double)remainder*4294967296.0/(double)period_us);
    return base_phase+advance;
}
void reanchor(uint64_t now) { base_phase=phase_at(now); anchor_us=now; }

void flash_program_cb(void *arg) {
    auto *pair=static_cast<std::pair<uint32_t,const uint8_t*>*>(arg);
    flash_range_program(pair->first,pair->second,PAGE_BYTES);
}
void flash_erase_cb(void *arg) {
    uint32_t offset=*static_cast<uint32_t*>(arg);
    flash_range_erase(offset,SECTOR_BYTES);
}

bool prepare_next_sector() {
    if (newest_page<0) return true;
    uint32_t next=(static_cast<uint32_t>(newest_page)+1)%PAGE_COUNT;
    // Erase the sector ahead while current valid records remain in the current
    // sector. Do this only under stable power, outside the emergency path.
    uint32_t page_in_sector=static_cast<uint32_t>(newest_page)%16;
    if (page_in_sector<8) return true;
    uint32_t sector_page=((static_cast<uint32_t>(newest_page)/16+1)%16)*16;
    if (erased(sector_page)) return true;
    uint32_t offset=JOURNAL_OFFSET+sector_page*PAGE_BYTES;
    int rc=flash_safe_execute(flash_erase_cb,&offset,1000);
    if (rc!=PICO_OK) {flash_error=true; return false;}
    return erased(sector_page);
}

bool append_record(uint64_t now, bool emergency) {
    uint32_t next= newest_page<0 ? 0 : (static_cast<uint32_t>(newest_page)+1)%PAGE_COUNT;
    // A brownout may leave a partly programmed page. Skip it rather than
    // making the journal permanently unwritable on the next boot.
    uint32_t searched=0;
    while (!erased(next) && searched++<PAGE_COUNT) next=(next+1)%PAGE_COUNT;
    if (searched>PAGE_COUNT || !erased(next)) { flash_error=true; return false; }
    alignas(PAGE_BYTES) Record r{};
    std::memset(&r,0xff,sizeof(r));
    r.magic=MAGIC; r.format=FORMAT; r.seq=journal_seq+1;
    r.period_us=period_us; r.phase_q32=phase_at(now); r.bipolar=bipolar?1:0;
    r.selected_unit=selected_unit;
    r.crc=crc32(reinterpret_cast<const uint8_t*>(&r),PAGE_BYTES-4);
    std::pair<uint32_t,const uint8_t*> args{JOURNAL_OFFSET+next*PAGE_BYTES,
        reinterpret_cast<const uint8_t*>(&r)};
    int rc=flash_safe_execute(flash_program_cb,&args,100);
    if (rc!=PICO_OK || !valid(*reinterpret_cast<const Record*>(page_address(next)))) {
        flash_error=true; return false;
    }
    newest_page=static_cast<int>(next); journal_seq=r.seq;
    if (!emergency) prepare_next_sector();
    return true;
}

uint32_t adc_mv(uint channel) {
    adc_select_input(channel);
    (void)adc_read(); // let the mux/source settle
    uint32_t sum=0;
    for (int i=0;i<4;++i) sum+=adc_read();
    return (sum*3300u*2u)/(4u*4095u);
}
void init_adc() {adc_init(); adc_gpio_init(BUCK_ADC); adc_gpio_init(CAP_ADC);}

void init_pwm() {
    for (uint gpio: {PWM_SINE,PWM_TRI,PWM_SQUARE}) gpio_set_function(gpio,GPIO_FUNC_PWM);
    uint slice_sine=pwm_gpio_to_slice_num(PWM_SINE);
    uint slice_square=pwm_gpio_to_slice_num(PWM_SQUARE);
    pwm_config cfg=pwm_get_default_config(); pwm_config_set_wrap(&cfg,PWM_TOP);
    pwm_init(slice_sine,&cfg,true); pwm_init(slice_square,&cfg,true);
}
void outputs(uint32_t phase) {
    double p=(double)phase/4294967296.0;
    double sine=0.5+0.5*std::sin(TAU*p);
    double tri=p<0.25 ? 0.5+2*p : (p<0.75 ? 1.5-2*p : 2*p-1.5);
    auto duty=[&](double value)->uint16_t {
        double d=bipolar?value:(0.5+0.5*value);
        return static_cast<uint16_t>(std::clamp(std::lround(d*PWM_TOP),0L,(long)PWM_TOP));
    };
    pwm_set_gpio_level(PWM_SINE,duty(sine));
    pwm_set_gpio_level(PWM_TRI,duty(tri));
    pwm_set_gpio_level(PWM_SQUARE,duty(p<0.5?1.0:0.0));
}

void init_leds() {
    uint offset=pio_add_program(led_pio,&ws_program);
    pio_sm_config c=pio_get_default_sm_config();
    sm_config_set_wrap(&c,offset,offset+3);
    sm_config_set_sideset(&c,1,false,false);
    sm_config_set_sideset_pins(&c,LED_PIN);
    sm_config_set_out_shift(&c,false,true,24);
    sm_config_set_fifo_join(&c,PIO_FIFO_JOIN_TX);
    sm_config_set_clkdiv(&c,(float)clock_get_hz(clk_sys)/(800000.0f*(WS_T1+WS_T2+WS_T3)));
    pio_gpio_init(led_pio,LED_PIN); pio_sm_set_consecutive_pindirs(led_pio,led_sm,LED_PIN,1,true);
    pio_sm_init(led_pio,led_sm,offset,&c); pio_sm_set_enabled(led_pio,led_sm,true);
}
using Frame = std::array<Color, MATRIX_CELLS>;

Color dim(Color c, double level) {
    level=std::clamp(level,0.0,1.0);
    return {static_cast<uint8_t>(std::lround(c.r*level)),
            static_cast<uint8_t>(std::lround(c.g*level)),
            static_cast<uint8_t>(std::lround(c.b*level))};
}

std::array<int, MATRIX_CELLS> charge_spiral() {
    std::array<int, MATRIX_CELLS> path{};
    int left=0,right=7,top=0,bottom=7,index=0;
    while (left<=right && top<=bottom) {
        for (int x=left;x<=right;++x) path[index++]=top*8+x;
        ++top;
        for (int y=top;y<=bottom;++y) path[index++]=y*8+right;
        --right;
        if (top<=bottom) {
            for (int x=right;x>=left;--x) path[index++]=bottom*8+x;
            --bottom;
        }
        if (left<=right) {
            for (int y=bottom;y>=top;--y) path[index++]=y*8+left;
            ++left;
        }
    }
    return path;
}

std::array<int, MATRIX_CELLS> pie_order() {
    std::array<int, MATRIX_CELLS> order{};
    for (int i=0;i<MATRIX_CELLS;++i) order[i]=i;
    auto angle=[](int i) {
        double a=std::atan2(static_cast<double>(i%8)-3.5,3.5-static_cast<double>(i/8));
        return a<0 ? a+TAU : a;
    };
    std::sort(order.begin(),order.end(),[&](int a,int b) {
        const double aa=angle(a),bb=angle(b);
        if (aa!=bb) return aa<bb;
        return std::hypot(a%8-3.5,a/8-3.5)<std::hypot(b%8-3.5,b/8-3.5);
    });
    return order;
}

uint32_t grb(Color c) {return (uint32_t(c.g)<<16)|(uint32_t(c.r)<<8)|c.b;}
void pixels(const Frame &frame) {
    // The matrix chain is routed in alternating rows. Keep logical art row-major.
    for (int i=0;i<MATRIX_CELLS;++i) {
        const int y=i/8, x=(y&1) ? 7-i%8 : i%8;
        pio_sm_put_blocking(led_pio,led_sm,grb(frame[y*8+x])<<8u);
    }
    sleep_us(80);
}
void blank() {pixels(Frame{});}

void render(uint64_t now, uint32_t cap_mv) {
    Frame frame{};
    const Color color=UNIT_COLOR[selected_unit];
    if (!reserve_ready) {
        static const auto spiral=charge_spiral();
        const double filled=std::clamp(static_cast<double>(cap_mv)/CAP_READY_MV,0.0,1.0)*64.0;
        const int complete=std::min(63,static_cast<int>(filled));
        for (int i=0;i<complete;++i) frame[spiral[i]]={2,8,14};
        frame[spiral[complete]]={23,27,28};
    } else if (mode_hold_preview) {
        for (int y=0;y<8;++y) for (int x=0;x<8;++x) {
            if (y<4) frame[y*8+x]={2,8,25};
            else if (bipolar) frame[y*8+x]={25,2,2};
        }
    } else if (display_view==1) {
        for (int u=0;u<4;++u) {
            int bx=(u&1)*4,by=(u/2)*4;
            for (int y=0;y<4;++y) for (int x=0;x<4;++x)
                frame[(by+y)*8+bx+x]=dim(UNIT_COLOR[u],u==selected_unit?1.0:0.10);
        }
    } else if (display_view==2 && selected_unit>=2) {
        const double filled=static_cast<double>(period_us)/(selected_unit==2?DAY_US:MONTH_US);
        for (int i=0;i<64;++i) frame[i]=dim(color,filled-i);
    } else if (display_view==2) {
        static const auto order=pie_order();
        const double filled=std::min(1.0,static_cast<double>(period_us)/MAXIMUM_US[selected_unit])*64.0;
        for (int i=0;i<64;++i) frame[order[i]]=dim(color,filled-i);
    } else {
        const int *path=bipolar?TRIANGLE_PATH_BI:TRIANGLE_PATH_UNI;
        const int count=bipolar?15:14;
        for (int i=0;i<count;++i) frame[path[i]]=dim(color,0.48);
        const int marker=std::min(count-1,static_cast<int>(static_cast<double>(phase_at(now))/4294967296.0*count));
        frame[path[marker]]={28,28,28};
    }
    if (flash_error || fallback_used) frame[63]={28,0,0};
    pixels(frame);
}

struct Encoder {
    uint8_t prev=3;
    int accum=0;
    bool raw_press=false, pressed=false, press_eligible=false;
    bool turned_during_press=false, mode_switched=false;
    uint64_t raw_change_us=0, press_us=0;

    void tick(uint64_t now) {
        if (!reserve_ready || power_failed) {
            press_eligible=false;
            mode_hold_preview=false;
        }
        uint8_t ab=(gpio_get(ENC_A)<<1)|gpio_get(ENC_B);
        static constexpr int8_t transitions[16]={0,-1,1,0, 1,0,0,-1, -1,0,0,1, 0,1,-1,0};
        accum+=transitions[(prev<<2)|ab]; prev=ab;
        if (accum>=4 || accum<=-4) {
            int dir=accum>0?1:-1; accum=0;
            if (pressed) {turned_during_press=true; mode_hold_preview=false;}
            if (reserve_ready && !power_failed) turn(dir,now);
        }
        bool raw=!gpio_get(ENC_PUSH);
        if (raw!=raw_press) {raw_press=raw; raw_change_us=now;}
        if (raw_press!=pressed && now-raw_change_us>=30000) {
            pressed=raw_press;
            if (pressed) {
                press_us=now; press_eligible=reserve_ready && !power_failed;
                turned_during_press=false; mode_switched=false;
            } else {
                mode_hold_preview=false;
                if (press_eligible && !turned_during_press && !power_failed &&
                    now-press_us<500000) {
                    selected_unit=(selected_unit+1)%4;
                    display_view=1; view_deadline_us=now+2000000;
                }
            }
        }
        if (pressed && press_eligible && !turned_during_press && reserve_ready && !power_failed) {
            const uint64_t held=now-press_us;
            mode_hold_preview=held>=500000;
            if (held>=2000000 && !mode_switched) {
                bipolar=!bipolar; mode_switched=true;
            }
        }
    }
    void turn(int dir,uint64_t now) {
        const int u=selected_unit;
        reanchor(now);
        if (period_us<MINIMUM_US[u]) period_us=MINIMUM_US[u];
        else if (period_us>MAXIMUM_US[u]) period_us=MAXIMUM_US[u];
        else {
            int64_t next=static_cast<int64_t>(period_us)+dir*static_cast<int64_t>(STEP_US[u]);
            period_us=static_cast<uint64_t>(std::clamp(next,static_cast<int64_t>(MINIMUM_US[u]),
                                                      static_cast<int64_t>(MAXIMUM_US[u])));
        }
        display_view=2; view_deadline_us=now+2000000;
    }
};
} // namespace

int main() {
    stdio_init_all();
    init_adc(); scan_journal();
    for (uint pin: {ENC_A,ENC_B,ENC_PUSH}) {gpio_init(pin); gpio_set_dir(pin,false); gpio_pull_up(pin);}
    init_pwm(); init_leds();
    Encoder encoder; next_checkpoint_us=time_us_64()+HOUR_US;
    uint64_t next_sample=0,next_display=0,next_wave=0;
    uint32_t cap_mv=0,buck_mv=0; int fail_count=0;
    while (true) {
        uint64_t now=time_us_64();
        if (now>=next_sample) {
            next_sample=now+2000;
            buck_mv=adc_mv(0); cap_mv=adc_mv(1);
            if (buck_mv<BUCK_FAIL_MV) ++fail_count; else fail_count=0;
            if (!power_failed && fail_count>=2) {
                power_failed=true;
                blank();
                if (reserve_ready) (void)append_record(time_us_64(),true);
                next_display=UINT64_MAX;
            }
            if (!reserve_ready && cap_mv>=CAP_READY_MV && buck_mv>=BUCK_RECOVER_MV) {
                reserve_ready=true; anchor_us=now;
                if (newest_page<0) (void)append_record(now,false);
                next_checkpoint_us=now+HOUR_US;
            }
            if (reserve_ready && cap_mv<CAP_READY_HYST_MV) {
                reanchor(now);
                reserve_ready=false;
            }
        }
        if (power_failed) {
            // A returning upstream supply is handled as a clean reboot; the
            // stored phase remains authoritative during the brownout window.
            if (buck_mv>BUCK_RECOVER_MV) watchdog_reboot(0,0,1);
            tight_loop_contents(); continue;
        }
        if (now>=next_wave) {
            next_wave=now+10000;
            outputs(reserve_ready?phase_at(now):base_phase);
        }
        encoder.tick(now);
        if (display_view!=0 && now>=view_deadline_us) display_view=0;
        if (now>=next_display) {next_display=now+100000; render(now,cap_mv);}
        if (reserve_ready && now>=next_checkpoint_us) {
            (void)append_record(now,false); next_checkpoint_us=now+HOUR_US;
        }
        tight_loop_contents();
    }
}

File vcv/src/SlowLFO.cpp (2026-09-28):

#include "plugin.hpp"

#include <algorithm>
#include <array>
#include <atomic>
#include <cmath>
#include <cstdint>
#include <string>

namespace {

constexpr double PI = 3.14159265358979323846;
constexpr int MATRIX_SIDE = 8;
constexpr int MATRIX_CELLS = MATRIX_SIDE * MATRIX_SIDE;
constexpr int64_t DAY = 86400;
constexpr int64_t MONTH = 30 * DAY;
constexpr int64_t MAX_PERIOD = 64 * MONTH;
constexpr int64_t MINIMUM[4] = {60, 3600, DAY, MONTH};
constexpr int64_t MAXIMUM[4] = {3600, DAY, 64 * DAY, MAX_PERIOD};
constexpr int64_t STEP[4] = {60, 3600, DAY / 2, MONTH};

struct Color {
    float r, g, b;
    constexpr Color(float red = 0.f, float green = 0.f, float blue = 0.f)
        : r(red), g(green), b(blue) {}
};

template <typename T>
T clampValue(T value, T lo, T hi) {
    return std::max(lo, std::min(value, hi));
}

constexpr Color UNIT_COLOR[4] = {
    {0.15f, 0.76f, 1.f},  // minutes: cyan
    {0.24f, 1.f, 0.45f},  // hours: green
    {1.f, 0.64f, 0.13f},  // days: amber
    {0.91f, 0.26f, 1.f},  // months: violet
};
constexpr int TRIANGLE_PATH_BI[] = {
    32, 24, 17, 9, 2, 11, 19, 28, 36, 45, 53, 62, 55, 47, 39
};
constexpr int TRIANGLE_PATH_UNI[] = {
    16, 8, 9, 1, 2, 3, 11, 12, 20, 21, 29, 30, 31, 23
};

std::array<int, MATRIX_CELLS> chargeSpiral() {
    std::array<int, MATRIX_CELLS> path{};
    int left = 0, right = MATRIX_SIDE - 1, top = 0, bottom = MATRIX_SIDE - 1;
    int index = 0;
    while (left <= right && top <= bottom) {
        for (int x = left; x <= right; ++x) path[index++] = top * MATRIX_SIDE + x;
        ++top;
        for (int y = top; y <= bottom; ++y) path[index++] = y * MATRIX_SIDE + right;
        --right;
        if (top <= bottom) {
            for (int x = right; x >= left; --x) path[index++] = bottom * MATRIX_SIDE + x;
            --bottom;
        }
        if (left <= right) {
            for (int y = bottom; y >= top; --y) path[index++] = y * MATRIX_SIDE + left;
            ++left;
        }
    }
    return path;
}

std::array<int, MATRIX_CELLS> pieOrder() {
    std::array<int, MATRIX_CELLS> order{};
    for (int i = 0; i < MATRIX_CELLS; ++i) order[i] = i;
    auto turn = [](int index) {
        const double x = index % MATRIX_SIDE - 3.5;
        const double y = 3.5 - index / MATRIX_SIDE;
        double angle = std::atan2(x, y);
        if (angle < 0) angle += 2.0 * PI;
        return angle;
    };
    std::sort(order.begin(), order.end(), [&](int a, int b) {
        const double aa = turn(a), bb = turn(b);
        if (aa != bb) return aa < bb;
        const double ra = std::hypot(a % MATRIX_SIDE - 3.5, a / MATRIX_SIDE - 3.5);
        const double rb = std::hypot(b % MATRIX_SIDE - 3.5, b / MATRIX_SIDE - 3.5);
        return ra < rb;
    });
    return order;
}

float clamp01(double x) {
    return static_cast<float>(clampValue(x, 0.0, 1.0));
}

void addColor(Color& dst, Color src, float brightness) {
    dst.r = std::min(1.f, dst.r + src.r * brightness);
    dst.g = std::min(1.f, dst.g + src.g * brightness);
    dst.b = std::min(1.f, dst.b + src.b * brightness);
}

double wave(int which, double phase) {
    phase -= std::floor(phase);
    if (which == 0)
        return 0.5 + 0.5 * std::sin(2.0 * PI * phase);
    if (which == 1) {
        if (phase < 0.25) return 0.5 + 2.0 * phase;
        if (phase < 0.75) return 1.5 - 2.0 * phase;
        return 2.0 * phase - 1.5;
    }
    return phase < 0.5 ? 1.0 : 0.0;
}

std::string periodLabel(int64_t seconds, int selectedUnit) {
    if (selectedUnit == 2 && seconds >= DAY && seconds <= 64 * DAY && seconds % (DAY / 2) == 0) {
        const std::string wholeDays = std::to_string(seconds / DAY);
        return wholeDays + (seconds % DAY ? ".5 d" : " d");
    }
    if (seconds >= MONTH && seconds % MONTH == 0)
        return std::to_string(seconds / MONTH) + " mo (30 d each)";
    if (seconds % DAY == 0) return std::to_string(seconds / DAY) + " d";
    if (seconds >= DAY) return std::to_string(seconds / DAY) + ".5 d";
    if (seconds % 3600 == 0) return std::to_string(seconds / 3600) + " h";
    if (seconds % 60 == 0) return std::to_string(seconds / 60) + " min";
    return std::to_string(seconds) + " s";
}

}  // namespace

struct SlowLFO : Module {
    enum OutputId { SINE_OUTPUT, TRIANGLE_OUTPUT, SQUARE_OUTPUT, OUTPUTS_LEN };

    std::atomic<int64_t> periodSeconds{60};
    std::atomic<double> phaseSnapshot{0.0};
    std::atomic<int> selectedUnit{0};
    std::atomic<int> displayView{0};  // 0 waveform, 1 selector, 2 time
    std::atomic<bool> bipolar{false};
    std::atomic<bool> modeHoldPreview{false};
    std::atomic<bool> simulatedOff{false};
    std::atomic<bool> charging{true};
    std::atomic<double> chargeProgress{0.0};
    std::atomic<int> chargeDurationSeconds{15};
    std::atomic<int> timeScale{1};

    std::atomic<int> pendingDetents{0};
    std::atomic<int> pendingShortPresses{0};
    std::atomic<int> pendingModeToggles{0};
    std::atomic<int> pendingPowerToggles{0};
    std::atomic<int> pendingPhaseQuarter{-1};
    std::atomic<bool> pendingRestore{false};
    std::atomic<double> restorePhase{0.0};

    double phase = 0.0;
    double chargeElapsed = 0.0;
    double uiClock = 0.0;
    double viewDeadline = 0.0;
    unsigned snapshotCounter = 0;

    SlowLFO() {
        config(0, 0, OUTPUTS_LEN);
        configOutput(SINE_OUTPUT, "Sine CV");
        configOutput(TRIANGLE_OUTPUT, "Triangle CV");
        configOutput(SQUARE_OUTPUT, "Square CV");
    }

    void process(const ProcessArgs& args) override {
        uiClock += args.sampleTime;
        if (pendingRestore.exchange(false)) {
            phase = clampValue(restorePhase.load(), 0.0, 0.999999999999);
            phaseSnapshot.store(phase);
        }

        if (pendingPowerToggles.exchange(0) & 1) {
            simulatedOff.store(!simulatedOff.load());
            chargeElapsed = 0.0;
            chargeProgress.store(0.0);
            charging.store(true);
            displayView.store(0);
        }
        const int forcedQuarter = pendingPhaseQuarter.exchange(-1);
        if (forcedQuarter >= 0) {
            phase = 0.25 * (forcedQuarter % 4);
            phaseSnapshot.store(phase);
        }

        const int presses = pendingShortPresses.exchange(0);
        if (presses > 0 && !simulatedOff.load() && !charging.load()) {
            selectedUnit.store((selectedUnit.load() + presses) % 4);
            displayView.store(1);
            viewDeadline = uiClock + 2.0;
        }
        const int modeToggles = pendingModeToggles.exchange(0);
        if ((modeToggles & 1) && !simulatedOff.load() && !charging.load()) {
            bipolar.store(!bipolar.load());
        }
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

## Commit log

2026-09-28 Create isolated SloLFO project snapshot
    [RevB-pricing-2026-09-24.xlsx, Slow-LFO-8HP-Carrier-RevB_2350.kicad_pcb, Slow-LFO-8HP-Faceplate_8x8.kicad_pcb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]
2026-09-28 Cancel held encoder action if reserve becomes unavailable
